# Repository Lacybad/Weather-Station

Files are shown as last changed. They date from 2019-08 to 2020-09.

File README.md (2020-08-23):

# Weather Station


This weather station uses an ESP8266 (WeMos D1 Mini), a TFT KMR-1.8 LCD display, a PIR
motion sensor, BJTs and a photoresistor for the display brightness, and an optional 1-wire
temperature sensor (no code for it right now).

This weather station uses darksky for the forecast with a free account. It displays the
current weather temperature, a high and low, and the next two days.

In Settings.h (or MiscSettings.h), add the GPS coordinates, wifi information, and timezone
to make the system work.

This project's PCB was made using JLCPCB. Using the cheapest shipping, it took 6 days to
LAX, a week in customs, and then 3-5 days to a location in the US.

## Icons / Other Code

The icons used for this project are from
[erikflowers](https://github.com/erikflowers/weather-icons).  Using the makefile command
`make imageConvert` converts the images in the folder weather-icons/svg to bmps in a data
folder. This folder can then be uploaded to the ESP8266 using the
[data-uploader](https://github.com/esp8266/arduino-esp8266fs-plugin), which uploads the
data in the /data folder to the SPIFFS file system. It is recommended if using the D1 mini
to have at least 1 MB of storage, and the images take up 124.0 KiB of space.

Other code for this project is from Bodmer's TFT\_eSPI library example for the
[BMP\_functions.ino](https://github.com/Bodmer/TFT_eSPI/blob/master/examples/Generic/TFT_SPIFFS_BMP/BMP_functions.ino),
and converted to work as a C++ library. The modified
[cpp](https://github.com/mwyoung/Weather-Station/blob/master/src/BMP_functions.cpp),
[h](https://github.com/mwyoung/Weather-Station/blob/master/src/BMP_functions.h) and
[license](https://github.com/mwyoung/Weather-Station/blob/master/src/BMP_functions_license.txt)
are in the src directory.

All other libraries (with given versions used) are not really modified from the source
(besides the [TFT\_eSPI v1.4.20](https://github.com/Bodmer/TFT_eSPI) for the pins and
display), and include [ESP8266 Board v2.5.2](https://github.com/esp8266/Arduino) with docs
[ESP8266Wifi and WiFiClientSecure](https://arduino-esp8266.readthedocs.io/en/latest/esp8266wifi/readme.html),
[ArduinoJson v6.13.0](https://github.com/bblanchon/ArduinoJson),
[BearSSL v1.4.0](https://github.com/arduino-libraries/ArduinoBearSSL),
[SPI - ESP8266](https://github.com/esp8266/Arduino/blob/master/libraries/SPI/SPI.h),
[Ticker - ESP8266](https://github.com/esp8266/Arduino/blob/master/libraries/Ticker/src/Ticker.h),
[Timezone v1.2.2](https://github.com/JChristensen/Timezone) and
[TimeLib v1.5.0](https://github.com/PaulStoffregen/Time).

## Data Source
This project originally used DarkSky as a source but moved to
[OpenWeatherMap](https://openweathermap.org/darksky-openweather) after DarkSky shut down
their API. The DarkSky branch in this repo contains the original code that was working
with that API.

## Schematic



For the PCB, the [d1\_mini\_kicad](https://github.com/jerome-labidurie/d1_mini_kicad)
library was used along with the
[digikey-kicad-library](https://github.com/Digi-Key/digikey-kicad-library) and a few
default libraries KiCad for the transistors. The parts can be found in the
[DigiKey purchase list](https://github.com/mwyoung/Weather-Station/blob/master/weatherPCB/DigikeyCartExample.csv),
and this csv file can be uploaded to digikey to buy the parts. Extra parts are included as
backup for buying parts along with buying a large quantity means cost savings. It is also
possible to use a check to save on shipping (could take an extra few days)

Other parts are from Amazon but can be bought on other sites or vendors if it is cheaper.
The parts include a [Wemos d1 mini](https://www.amazon.com/gp/product/B076F53B6S/),
[Photoresistors](https://www.amazon.com/gp/product/B01N0GJ6QP/),
[IR PIR Motion Sensor](https://www.amazon.com/gp/product/B07LF47TRC/),
[LCD Display](https://www.amazon.com/gp/product/B00LSG51MM/),
[Project Boxes](https://www.amazon.com/dp/B07V7X11LJ).

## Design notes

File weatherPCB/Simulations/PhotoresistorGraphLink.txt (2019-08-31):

https://www.desmos.com/calculator/svxpvmprhs

Note: https://wiki.wemos.cc/_media/products:d1:mini_new_v2_2_0.pdf
Wemos D1 mini has a 1.0V ADC, but on A0 has a voltage divider (220k and 100k) to 1.03V

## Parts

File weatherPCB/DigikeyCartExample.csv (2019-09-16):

Index | Quantity | Part Number | Manufacturer Part Number | Description | Customer Reference | Available | Backorder | Unit Price | Extended Price USD
1 | 10 | 478-3188-ND | SR215C104KAR | CAP CER 0.1UF 50V X7R RADIAL |  | 10 | 0 | 0.135 | 1.35
2 | 10 | 2N4401-APCT-ND | 2N4401-AP | TRANS NPN 40V TO92 |  | 10 | 0 | 0.17 | 1.7
3 | 10 | 2N4403-APCT-ND | 2N4403-AP | TRANS PNP 40V TO92 |  | 10 | 0 | 0.17 | 1.7
4 | 50 | CF14JT220RCT-ND | CF14JT220R | RES 220 OHM 1/4W 5% AXIAL |  | 50 | 0 | 0.022 | 1.1
5 | 50 | CF14JT4K70CT-ND | CF14JT4K70 | RES 4.7K OHM 1/4W 5% AXIAL |  | 50 | 0 | 0.022 | 1.1
6 | 50 | CF14JT10K0CT-ND | CF14JT10K0 | RES 10K OHM 1/4W 5% AXIAL |  | 50 | 0 | 0.022 | 1.1
7 | 10 | S7036-ND | PPPC031LFBN-RC | CONN HDR 3POS 0.1 GOLD PCB |  | 10 | 0 | 0.351 | 3.51

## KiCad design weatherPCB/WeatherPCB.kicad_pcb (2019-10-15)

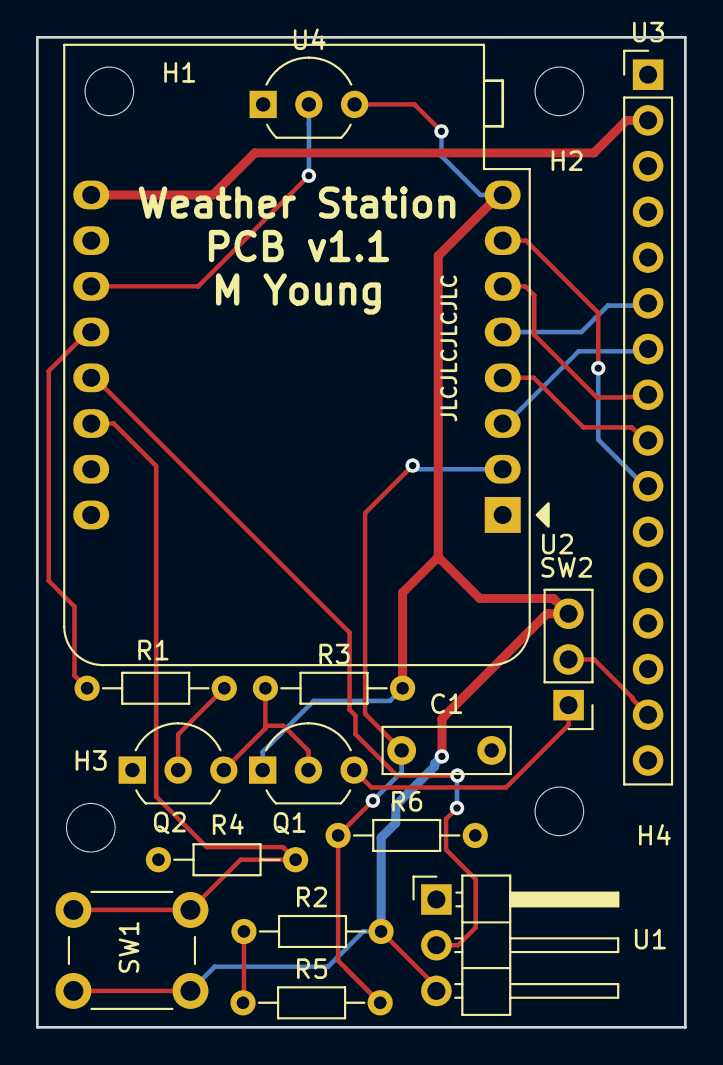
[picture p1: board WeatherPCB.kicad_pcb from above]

Board: 2 copper layers, 36.0 x 55.0 mm, 19 parts (0 on the bottom side), 18 nets.

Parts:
C1: 0.1u; C_Disc_D7.0mm_W2.5mm_P5.00mm
H1, H2, H3, H4: MountingHole; MountingHole_2.7mm
Q1: 2N4403-ND; TO-92_Inline_Wide
Q2: 2N4401-ND; TO-92_Inline_Wide
R1, R3: 4.7k; R_Axial_DIN0204_L3.6mm_D1.6mm_P7.62mm_Horizontal
R2: 220; R_Axial_DIN0204_L3.6mm_D1.6mm_P7.62mm_Horizontal
R4, R6: 10k; R_Axial_DIN0204_L3.6mm_D1.6mm_P7.62mm_Horizontal
R5: 70-36k; R_Axial_DIN0204_L3.6mm_D1.6mm_P7.62mm_Horizontal
SW1: SW_Push; SW_PUSH_6mm_h5mm
SW2: SW_SPDT; Pin_Header_Straight_1x03_Pitch2.54mm
U1: PIR_MTN_SNR; Pin_Header_Angled_1x03_Pitch2.54mm
U2: WeMos_mini; WEMOS_D1_mini_light
U3: TFTLCD_ST7735R; Pin_Header_Straight_1x16_Pitch2.54mm
U4: DS1822; TO-92_Inline_Wide

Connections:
+3V3: Q1.1, R2.1, R3.2, SW1.1, SW2.3, U1.3, U2.8, U4.3
+5V: U2.9, U3.2
GND: C1.2, Q2.1, R4.2, R6.2, U1.1, U2.10, U3.1, U3.16, U4.1
unnamed: C1.1, R5.2, R6.1, U2.2
unnamed: Q1.2, Q2.3, R3.1
unnamed: Q1.3, SW2.1
unnamed: Q2.2, R1.1
unnamed: R1.2, U2.12
unnamed: R2.2, R5.1
unnamed: R4.1, SW1.2, U2.14
unnamed: SW2.2, U3.15
unnamed: U1.2, U2.13
unnamed: U2.3, U3.7
unnamed: U2.4, U3.9
unnamed: U2.5, U3.6
unnamed: U2.6, U3.8
unnamed: U2.7, U3.10
unnamed: U2.11, U4.2

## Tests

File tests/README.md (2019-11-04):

# Examples used to test certain functions for the Weather program

TFT\_Display - Used to test the display, height, pwm, and photoresistor

Motion - Used to test the pir motion sensor

BearSSL\_Weather - Used to test the certificate of the Darksky website

[SPIFFS\_REMOVE\_ALL](https://github.com/mwyoung/SPIFFS_Remove_All)

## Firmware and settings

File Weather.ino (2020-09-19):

/*
    Weather with display
    Miles Young, 2019-2020
 */

//Wifi
#include <ESP8266WiFi.h>
#include <WiFiClientSecure.h>
#include <ArduinoJson.h>
#include "src/weatherClass.h"
//#include "src/cert.h"       //location for cert in memory
#include "Settings.h"       //settings file
//display //drivers - greentab, blacktab+inversion(orange)
//For TFT_eSPI, in User_Setup.h, set TFT_DC PIN_D0 and TFT_RST PIN_D6
#include <TFT_eSPI.h> //!!D6=RST!!,!!D0=A0/DC!!,D8=CS,D7=SDA,D5=SCL
#include <SPI.h>
#include "src/BMP_functions.h"
#include <Ticker.h> //timer interrupts for brightness
//file system
//use fs::File for SPIFFS, sd::File for SD if needed
#define FS_NO_GLOBALS
#include <FS.h>

#include <Timezone.h>
#include <TimeLib.h>

/* include a MiscSettings.h or Settings.h file for these defs
STASSID, STAPSK, API_KEY, FORECAST_LOC, UPDATE_INTERVAL, PIR_TIME,
PIR_ON_TIME, PIR_OFF_TIME, DAYLIGHT_RULE_CONFIG, STANDARD_RULE_CONFIG
*/
//uncomment to print debug, from https://forum.arduino.cc/index.php?topic=46900.0
//hint - when debugging, change the times to trigger things faster...
//#define DEBUG
#ifdef DEBUG
    //#define SHOW_BRIGHTNESS
    //#define SHOW_MOTION
    #define DEBUG_PRINT(str)    Serial.print(str)
    #define DEBUG_PRINTLN(str)  Serial.println(str)
#else
    #define DEBUG_PRINT(str)
    #define DEBUG_PRINTLN(str)
#endif

//uncomment for approx temp (can be 10 deg inaccurate vs other sources)
//#define TEMPAPPROX

//display constants
#define DP_W 128        //display used, need to change if using different size
#define DP_HALF_W (DP_W >> 1)
#define DP_H 160
#define DP_HALF_H (DP_H >> 1)
#define LARGE_ICON 44
#define SMALL_ICON 20
#define TIME_ICON 8     //size of time XX:XX XM
#define FS1 8           //font size height 1
#define FSX1 6          //font size width 1
#define FS2 16
#define FSX2 8
#define FS4 26          //could be 32
//FS6=48, FS7=56/48, FS8=56/75  //either or
#define displayUpdate 1000  //in ms
#define pwmShift 9          //also change brightness max
#define pwmJump 8           //min difference
#define pwmRange (1<<pwmShift)-1 //max range
#define pwmFreq 1000      //1kHz frequency
#define pwmOut D3       //output pin for brightness
#define pirPin D2
#define buttonPin D1
#define UNIX_SECOND 1000UL //1000 uS
#define UNIX_MINUTE UNIX_SECOND*60UL
#define DELAYTIME 20*UNIX_MINUTE

// Constant variables
const char *ssid = STASSID;
const char *password = STAPSK;
const char *host = "api.openweathermap.org";
#ifdef USE_CERT
    const int httpsPort = 443;
    const String httpsProtocol="HTTP/1.1";
#else
    const int httpsPort = 80; //is http
    const String httpsProtocol="HTTP/1.0";
#endif
const size_t capacity = 8*JSON_ARRAY_SIZE(1) + JSON_ARRAY_SIZE(2) + JSON_ARRAY_SIZE(8) +
    18*JSON_OBJECT_SIZE(4) + 9*JSON_OBJECT_SIZE(6) + 5*JSON_OBJECT_SIZE(14) +
    4*JSON_OBJECT_SIZE(15) + 4000;

const String forecastType = "/data/2.5/onecall";
//const String FORECAST_LOC //see define location
const String forecastDetails = "exclude=minutely,hourly,flags,alerts";
const String forecastStr = forecastType + "?" + FORECAST_LOC + "&" + forecastDetails +
    "&units=" + UNITS + "&appid=" + API_KEY;

#define SUNRISE_ICON "sunrise"
#define SUNSET_ICON "sunset"

//global variables - modifiable
TFT_eSPI tft = TFT_eSPI(); //start library
Ticker tftBrightness;

//weather variables
Weather currentWeather;
#define dailyWeatherSize 3
Weather dailyWeather[dailyWeatherSize]; //weather for today, tomorrow, and day+1
int16_t timezoneOffset = 0;
bool haveSetup = false;

//display vars
uint16_t cursorX;
uint16_t cursorY;
char displayOutput[10];
volatile uint16_t rawBrightness; //10 bit number
volatile uint16_t newBrightness;
volatile uint16_t oldBrightness = 1;
volatile bool displayOn = false;

//motion vars
volatile unsigned long lastUpdateTime = 0;
volatile unsigned long currentTime = 0;
volatile unsigned long currentLocalTime = 0; //if not getting ntp time
volatile uint8_t currentHour = 0;
volatile unsigned long pirTime = 0; //last updated
bool pirLast = LOW;
bool pirInput = LOW;
bool buttonLast = LOW;
bool buttonInput = LOW;

//function defs
void LED(bool led_output);
void updateBrightness();
void displayOnOff();
void setBrightness(uint8_t newBrightness);
void setup();
void loop();
void startWeather();
void setClock();
bool getWeather();
void printWeatherDisplay();
inline void printTFTSpace(uint8_t i);
void timeLocalStr(time_t getTime);
void timeStr(time_t getTime);
void setLocalTime(time_t getLocalTime);
void colorPrecip(int color);
void colorPrecipIntensity(float color);
void colorBlueBounds(uint16_t blueAmt);
void colorHumid(int color);
void printPrecip(const String typeWater, int water, uint8_t space);
void printPrecipIntensity(float waterAmt, uint8_t space);
void printHumid(const String typeWater, int water, uint8_t space);
void colorTemp(int color);
int getColorTemp(int color);
void printTempCenter(int tempH, int tempL, uint8_t space, uint8_t fontSize,
        uint8_t textWidth);
void printTemp(int tempH, int tempL, uint8_t space);
inline uint16_t rgbToHex(uint8_t red, uint8_t green, uint8_t blue);
bool printWeatherSerial();
void printIcon(const char *icon);
int checkWeatherIcon(const char *icon);
inline void clearScreen(int textSize);
void flashScreen();
void connectToWifi();
void disconnectWifi();

//flips the LED, is a wrapper function due to ESP8266 having inverse LED
void LED(bool led_output){
    digitalWrite(LED_BUILTIN, !led_output); //need to flip the led
}

//updates the current brightness, changes slowly
void updateBrightness(){
    rawBrightness = analogRead(A0);
    newBrightness = rawBrightness>>(10-pwmShift); //change range: 0-2^(10-x) range

    if (newBrightness < 1){
        newBrightness = 1; //never be zero or else off
    }
    //jump function
    if (abs(newBrightness-oldBrightness) > pwmJump){
        oldBrightness = newBrightness; //jump if large difference
    }
    if (newBrightness > oldBrightness){
        oldBrightness++;
    }
    else if (newBrightness < oldBrightness){
        oldBrightness--;
    }
    setBrightness(oldBrightness);
    //else - no change
#ifdef SHOW_BRIGHTNESS
    DEBUG_PRINT("b: ");
    DEBUG_PRINT(newBrightness);
#endif
}

//turns the display off (along with brightness) or on
void displayOnOff(){
    if (displayOn == false){
        DEBUG_PRINTLN("Turning display on");
        tftBrightness.attach_ms(displayUpdate, updateBrightness); //call every 500ms
        flashScreen(); //clear screen
        updateBrightness();
        displayOn = true;
#ifdef DEBUG
        LED(true);
#endif
    }
    else {
        DEBUG_PRINTLN("Turning display off");
        tftBrightness.detach();
        flashScreen(); //clear screen
        setBrightness(0);
        displayOn = false;
#ifdef DEBUG
        LED(false);
#endif
    }
}

//force sets the brightness of the display
void setBrightness(uint8_t newBrightness){
    analogWrite(pwmOut, newBrightness);
}

//initial setup of the program
void setup() {
    pinMode(LED_BUILTIN, OUTPUT); //LED, GPIO 2, D4
    LED(HIGH);

#ifdef DEBUG
    Serial.begin(115200);
    DEBUG_PRINTLN("\nStartup");
    DEBUG_PRINT("Brightness range: ");
    Serial.println(pwmRange, BIN);
#endif

    wifi_set_sleep_type(MODEM_SLEEP_T); //just turns off WiFi temporary

    analogWriteRange(pwmRange); //display brightness setup
    analogWriteFreq(pwmFreq);
    pinMode(pwmOut, OUTPUT);
    analogWrite(pwmOut, 1); //start at lowest brightness
    displayOn = false;
    displayOnOff();
    tft.init(); //start display
    tft.setRotation(2);

    clearScreen(2); //start at top, font size 2
    if ((tft.width() != DP_W) && (tft.height() != DP_H)){
        DEBUG_PRINT("DISPLAY FORMATTING NOT GUARANTEED");
    }

    if (!SPIFFS.begin()){
        DEBUG_PRINTLN("SPIFFS init failed...");
        while (1) { delay(1); } //stop program
    }
    DEBUG_PRINTLN("SPIFFS init");

#ifdef PIR_TIME
    pinMode(pirPin, INPUT);
#endif
    pirTime = millis(); //for right now, blank value
    pinMode(buttonPin, INPUT);
    LED(LOW);

    connectToWifi();
    startWeather();
#ifdef DEBUG
    tft.setCursor(DP_W-8,0,1);
    tft.print("s");
    currentHour = hour(now());
    DEBUG_PRINT("Hour: "); DEBUG_PRINTLN(currentHour);
#endif
}

//Checks for motion, button press, and update time
void loop() {
    currentTime = millis(); //time since started

#ifdef PIR_TIME
    currentHour = hour(now());
#ifdef PIR_OFF_TIME_MORNING
    if (currentHour >= PIR_ON_TIME || currentHour < PIR_OFF_TIME){ //only during day
#else
    if (currentHour >= PIR_ON_TIME && currentHour < PIR_OFF_TIME){ //only during day
#endif
        pirInput = digitalRead(pirPin);

        if ((pirInput == HIGH) && (pirLast == LOW)){
           //turn on display...
            pirTime = millis();

            if (displayOn == false){
                displayOnOff();
                printWeatherDisplay(); //just turned on...
                DEBUG_PRINTLN("Display Motion Updated...");
            }
#ifdef UPDATE_INTERVAL_MOTION
            if ((lastUpdateTime + UPDATE_INTERVAL_MOTION*UNIX_MINUTE) <= currentTime){
#else
            if ((lastUpdateTime + UPDATE_INTERVAL*UNIX_MINUTE) <= currentTime){
#endif
                DEBUG_PRINTLN("Motion update");
                startWeather(); //only get new data after a period
            }
#ifdef DEBUG
            tft.setCursor(DP_W-8,0,1);
            tft.print("m");
#ifdef SHOW_MOTION
            DEBUG_PRINT("M ");
#endif
#endif
        }
        pirLast == pirInput; //move to last
    }
    else {
        delay(450); //longer sleep at night
    }
#endif
    //turn off if no motion for a while, always (no sleep hours)
    if ((displayOn == true) && ((pirTime + PIR_TIME*UNIX_SECOND) <= currentTime)){
        DEBUG_PRINTLN("Auto turnoff");
        displayOnOff(); //not triggered for a while
    }

    //button function
    buttonInput = digitalRead(buttonPin);
    if ((buttonInput == HIGH) && (buttonLast == LOW)){
        DEBUG_PRINTLN("Button Pressed");
        if (displayOn == false){
            displayOnOff();
        }
        startWeather(); //force get new data
#ifdef DEBUG
        tft.setCursor(DP_W-8,0,1);
        tft.print("b");
#endif
    }
    buttonLast = buttonInput; //update

    if ((lastUpdateTime + UPDATE_INTERVAL*UNIX_MINUTE) <= currentTime){
        DEBUG_PRINTLN("Auto updated");
        //flashScreen(); //don't clear screen yet
        startWeather();
#ifdef DEBUG
        tft.setCursor(DP_W-8,0,1);
        tft.print("a");
#endif
    }
    delay(50);
}

//checks the parsing of the weather, updates display and update time
void startWeather(){
    bool output = getWeather();
    if (output == true){
        if(haveSetup){
            DEBUG_PRINTLN("----------\nFlash display");
            flashScreen(); //flash screen to refresh colors, not on boot
        }

        printWeatherDisplay();
        printWeatherSerial();
        pirTime = millis(); //update last time updated
        lastUpdateTime = millis();
    }
    else {
        DEBUG_PRINTLN("Parse FAILED");
    }
}

//set time via NTP, for tls (X.509) certificate
//From ESP8266 example HTTPSRequestCSCertAxTLS
void setClock() {
    DEBUG_PRINT("Setting time using SNTP: ");
    //timezone, daylightoffset, servers
    configTime(0, 0, "pool.ntp.org", "time.nist.gov"); //utc time
    time_t now = time(nullptr);
    while (now < 8 * 3600 * 2) {
        delay(500);
        DEBUG_PRINT(".");
        now = time(nullptr);
    }
    DEBUG_PRINTLN("");
    setLocalTime(now);
    //struct tm timeinfo;
    //gmtime_r(&now, &timeinfo);
    //DEBUG_PRINT("Current time: ");
    //DEBUG_PRINT(asctime(&timeinfo));
}

//gets the weather from api, formats json
bool getWeather() {
    tft.fillRect(0,DP_H-FS1, DP_W, FS1, TFT_BLACK); //clear line
    tft.setCursor(0,DP_H-FS1,1);
    tft.println("Src: OpenWeatherMap");

#ifdef USE_CERT
    DEBUG_PRINTLN("Setting up cert");
    BearSSL::WiFiClientSecure client;
    BearSSL::X509List cert(digicert);
    client.setTrustAnchors(&cert);
    //client.setInsecure(); //no https

    setClock(); //set clock, update when getting new as drift occurs on uC
#else
    // Connect to remote server
    WiFiClient client;
#endif

    DEBUG_PRINT("connecting to ");
    DEBUG_PRINTLN(host);
    if (!client.connect(host, httpsPort)) {
        DEBUG_PRINTLN("Connection failed");
        tft.fillRect(0,DP_H-FS1, DP_W, FS1, TFT_BLACK); //clear line
        tft.setCursor(0,DP_H-FS1,1);
#ifdef USE_CERT
        tft.println("Connection fail\nCould be cert fail");
#else
        tft.println("Connection fail");
#endif
        client.stop();
        if(displayOn == true){
            setBrightness(5);
        }
        delay(DELAYTIME); //stop for delay time
        ESP.restart(); //restart to avoid loop
        return false; //should never get here
    }
    else {
        DEBUG_PRINTLN("Getting forecast for: ");
        DEBUG_PRINTLN("https://" + String(host) + forecastStr);

        client.print(String("GET ") + forecastStr + " " + httpsProtocol + "\r\n" +
                "Host: " + host + "\r\n" +
                "User-Agent: ESP8266\r\n" +
                "Connection: close\r\n\r\n");

        DEBUG_PRINTLN("request sent");
        while (client.connected() || client.available()) {
            if (client.available()){
                String line = client.readStringUntil('\n');
                //DEBUG_PRINTLN(line); //print header
                if (line == "\r") {
                    DEBUG_PRINTLN("headers received");
                    tft.fillRect(0,DP_H-FS1, DP_W, FS1, TFT_BLACK); //clear line
                    tft.setCursor(0,DP_H-FS1,1);
                    tft.print("Got forecast");
                    break;
                }
            }
        }
    }

    //help from https://arduinojson.org/v6/assistant/
    DEBUG_PRINT("Created doc with size:"); DEBUG_PRINT(capacity); DEBUG_PRINT(" -> ");
    DynamicJsonDocument doc(capacity);
    tft.println("...");
    DeserializationError error = deserializeJson(doc, client.readStringUntil('\n'));
    tft.println("...");
    tft.setCursor(0,DP_HALF_H,1);
    DEBUG_PRINT("Parse Status: ");

    if (error){
        DEBUG_PRINT("Parse failed - ");
        DEBUG_PRINTLN(error.c_str());
        tft.println("JSON parse failed");
        tft.println(error.c_str());
        delay(DELAYTIME);
        return false;
    }
    else {
        //check if can get any key
        DEBUG_PRINTLN("Parse succeeded");
        const char *error = doc["timezone"];
        if (error == NULL){
            DEBUG_PRINT("Checking if message exists: ");
            const char *msg = doc["message"];
            if (msg != NULL){
                DEBUG_PRINTLN(msg);
                clearScreen(1);
                tft.println(msg);
            }
            return false;
        }
    }

    DEBUG_PRINTLN("Getting Data");
    bool output = currentWeather.setupWeather(doc["current"], false);
    if (output == false){
        DEBUG_PRINTLN("Setup failed for current");
        return false;
    }
    else {
        DEBUG_PRINTLN("Setup current");
    }

    timezoneOffset = doc["timezone_offset"];
    //setTime(currentWeather.getTime());
    setLocalTime(currentWeather.getTime()); //set time
    timeLocalStr(currentWeather.getTime());
    DEBUG_PRINT(timezoneOffset); DEBUG_PRINT(" "); DEBUG_PRINT(currentWeather.getTime());
        DEBUG_PRINT(" -> "); DEBUG_PRINTLN(displayOutput);

    //is a work-around - sometimes does not get the icon string correctly after wakeup
    DEBUG_PRINT(" "); DEBUG_PRINTLN(currentWeather.getIcon());

    for (int i=0; i<dailyWeatherSize; i++){
        output = dailyWeather[i].setupWeather(doc["daily"][i], true);
        if (output == false){
            DEBUG_PRINTLN("Setup failed for daily");
            return false;
        }
        else {
            DEBUG_PRINT("Setup daily ");
        }
    }

    DEBUG_PRINTLN("\nDone!");
    lastUpdateTime = millis();
    client.stop();
    return true;
}

//outputs weather to the display
void printWeatherDisplay(){
    clearScreen(1);
    uint16_t iconY = 0;
    uint16_t iconX = 0;
    int tempVal = 0;
    int tempHigh = 0;
    int tempLow = 0;
    if(!currentWeather.getSetup()){
        tft.println("Not setup");
        return;
    }

    //current weather
    tft.setCursor(tft.getCursorX()+1, tft.getCursorY());
    tft.print("Updated: ");
    timeLocalStr(currentWeather.getTime());
    tft.println(displayOutput);
    cursorY = tft.getCursorY();
    tft.setCursor((DP_HALF_W - LARGE_ICON)>>1, cursorY+1);
    printIcon(currentWeather.getIcon());

    //Current Temp
    //tft.setCursor(DP_HALF_W, cursorY+FS1-1, 2); tft.print("~");
    tft.setCursor(DP_HALF_W, cursorY, 4);
    //colorTemp(currentWeather.getTemp());
#ifdef TEMPAPPROX
    tft.print(currentWeather.getTempApprox());
#else
    tft.print(currentWeather.getTemp());
#endif
    tft.setTextColor(TFT_WHITE);
    tft.drawCircle(tft.getCursorX()+4, tft.getCursorY()+4, 2, TFT_WHITE); //degree symbol
    tft.setCursor(tft.getCursorX()+10, tft.getCursorY(), 2);
    tft.println("F");
    tft.setCursor(DP_HALF_W, tft.getCursorY()+(FS1>>1)+1, 1);
    printPrecip("Rain:", currentWeather.getPrecipProb(), 2);

    //Temp high/low
    tft.setCursor(DP_HALF_W, tft.getCursorY()+FS1-1, 2);
    printTemp(dailyWeather[0].getTempHigh(), dailyWeather[0].getTempLow(), 4);
    tft.println();

    //Rain/Humidity
    tft.setCursor(tft.getCursorX()+4, tft.getCursorY()-(FS1>>2), 2);
    printPrecip("Rain:", dailyWeather[0].getPrecipProb(), 4);
    tft.setCursor(DP_HALF_W+8, tft.getCursorY());
#ifdef PRECIP_INSTY
    printPrecipIntensity(dailyWeather[0].getPrecipAmt(), 4);
#else
    printHumid("RH:", dailyWeather[0].getHumidity(), 4);
#endif
    tft.println();
    tft.setTextColor(TFT_WHITE);

    //set sunset/rise
    cursorY = tft.getCursorY();
    tft.setCursor(4,cursorY,1);
    timeLocalStr(dailyWeather[0].getSunriseTime());
    tft.println(displayOutput);
    tft.setCursor(DP_HALF_W + (SMALL_ICON>>1)+2, cursorY);
    timeLocalStr(dailyWeather[0].getSunsetTime());
    tft.println(displayOutput);
    cursorY = tft.getCursorY();

    tft.setCursor(DP_HALF_W-(SMALL_ICON>>1), cursorY-(SMALL_ICON>>1)); //divide 2
    if (currentWeather.getTime() < dailyWeather[0].getSunriseTime() ||
            currentWeather.getTime() > dailyWeather[0].getSunsetTime()){
        printIcon(SUNRISE_ICON); //is after sunset or before sunrise
        tft.drawLine(4, cursorY, DP_HALF_W - (SMALL_ICON>>1) - 4, cursorY, TFT_WHITE);
    }
    else {
        printIcon(SUNSET_ICON); //is after sunrise
        tft.drawLine(DP_HALF_W+(SMALL_ICON>>1) + 4, cursorY, DP_W - 4, cursorY, TFT_WHITE);
    }

    tft.setCursor(tft.getCursorX(), tft.getCursorY()+FS1-1);

    //Add some color - draw current temp as a rect, x0,y0,x1,y1
    tft.fillRect(DP_W-2, 0, DP_W, DP_HALF_H-(FS2<<1), getColorTemp(currentWeather.getTempApprox()));

    //next day forecast
    tft.setTextColor(TFT_WHITE);
    cursorY = FS1 + FS4 + (FS2<<1) + FS2 + FS1;
    tft.drawLine(DP_HALF_W - 1, cursorY - (FS1>>2), DP_HALF_W - 1, DP_H - (FS1>>2), TFT_DARKGREY);

    tft.setCursor(8,cursorY - (FS1>>1)+1);
    printIcon(dailyWeather[1].getIcon());
    tft.setCursor(DP_HALF_W+8,tft.getCursorY());
    printIcon(dailyWeather[2].getIcon());

    tft.setCursor(20, cursorY - FS2, 2);
    tft.print(dayShortStr(weekday(dailyWeather[1].getTime())));
    tft.setCursor(DP_HALF_W+20, tft.getCursorY());
    tft.print(dayShortStr(weekday(dailyWeather[2].getTime())));

    tft.setCursor(0,cursorY + (LARGE_ICON - (FS1>>1)));
    printTempCenter(dailyWeather[1].getTempHigh(), dailyWeather[1].getTempLow(), 1,
            FSX2, DP_HALF_W);

    tft.setCursor(DP_HALF_W,tft.getCursorY());
    printTempCenter(dailyWeather[2].getTempHigh(), dailyWeather[2].getTempLow(), 1,
            FSX2, DP_HALF_W);
    tft.println();

    tft.setCursor(4+1,tft.getCursorY()-1,1);
    printPrecip("Rain:", dailyWeather[1].getPrecipProb(), 4);
    tft.setCursor(DP_HALF_W+2+1,tft.getCursorY());
    printPrecip("Rain:", dailyWeather[2].getPrecipProb(), 4);
    tft.println();

    tft.setCursor(4+1,tft.getCursorY());
#ifdef PRECIP_INSTY
    printPrecipIntensity(dailyWeather[1].getPrecipAmt(), 4);
#else
    printHumid("RH:", dailyWeather[2].getHumidity(), 4);
#endif
    tft.setCursor(DP_HALF_W+2+1,tft.getCursorY());
#ifdef PRECIP_INSTY
    printPrecipIntensity(dailyWeather[2].getPrecipAmt(), 4);
#else
    printHumid("RH:", dailyWeather[2].getHumidity(), 4);
#endif
    tft.println();
    tft.setTextColor(TFT_WHITE);

    haveSetup = true;
}

//prints a variable size space
inline void printTFTSpace(uint8_t i){
    tft.setCursor(tft.getCursorX()+i,tft.getCursorY());
}

//converts UTC to timezone
void timeLocalStr(time_t getTime){
    timeStr(getTime + timezoneOffset);
}

//converts a time to AM/PM
void timeStr(time_t getTime){
    snprintf(displayOutput, sizeof(displayOutput), "%02d:%02d ",
            hourFormat12(getTime), minute(getTime));
    if (isAM(getTime)){
        strncat(displayOutput,"AM", 2);
    }
    else {
        strncat(displayOutput, "PM", 2);
    }
}

//sets the current local time
void setLocalTime(time_t getLocalTime){
    currentLocalTime = getLocalTime + timezoneOffset;
    setTime(currentLocalTime);
#ifdef debug
    DEBUG_PRINTLN("Set local time to:");
    timeStr(getLocalTime);
    DEBUG_PRINT(displayOutput);
#endif
}

//changes the color of rain to stand out more
void colorPrecip(int color){
    if (color > 40){
        colorBlueBounds(color>>2);
    }
    else {
        tft.setTextColor(TFT_WHITE);
    }
}

//changes the color of rain to stand out more
void colorPrecipIntensity(float color){
    if (color >= 0.01){
        colorBlueBounds((uint16_t)color*100);
    }
    else {
        tft.setTextColor(TFT_WHITE);
    }
}

//checks bounds of colors
void colorBlueBounds(uint16_t blueAmt){
    if (blueAmt > 255){
        blueAmt = 255;
    }
    tft.setTextColor(rgbToHex(0, 255 - blueAmt, 255));
}
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

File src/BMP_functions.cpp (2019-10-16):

#include <FS.h>
#include <TFT_eSPI.h>
#include "BMP_functions.h"
extern TFT_eSPI tft;
// Bodmers BMP image rendering function
// changed to output errors

int8_t drawBmp(const char *filename, int16_t x, int16_t y) {

    if ((x >= tft.width()) || (y >= tft.height())) return 0;

    fs::File bmpFS;

    // Open requested file on SD card
    bmpFS = SPIFFS.open(filename, "r");

    if (!bmpFS)
    {
        Serial.println("File not found");
        return 0;
    }

    int returnVal = 0;
    uint32_t seekOffset;
    uint16_t w, h, row, col;
    uint8_t  r, g, b;

    uint32_t startTime = millis();

    if (read16(bmpFS) == 0x4D42)
    {
        read32(bmpFS);
        read32(bmpFS);
        seekOffset = read32(bmpFS);
        read32(bmpFS);
        w = read32(bmpFS);
        h = read32(bmpFS);

        if ((read16(bmpFS) == 1) && (read16(bmpFS) == 24) && (read32(bmpFS) == 0))
        {
            y += h - 1;

            tft.setSwapBytes(true);
            bmpFS.seek(seekOffset);

            uint16_t padding = (4 - ((w * 3) & 3)) & 3;
            uint8_t lineBuffer[w * 3 + padding];

            for (row = 0; row < h; row++) {
                bmpFS.read(lineBuffer, sizeof(lineBuffer));
                uint8_t*  bptr = lineBuffer;
                uint16_t* tptr = (uint16_t*)lineBuffer;
                // Convert 24 to 16 bit colours
                for (uint16_t col = 0; col < w; col++)
                {
                    b = *bptr++;
                    g = *bptr++;
                    r = *bptr++;
                    *tptr++ = ((r & 0xF8) << 8) | ((g & 0xFC) << 3) | (b >> 3);
                }

                // Push the pixel row to screen, pushImage will crop the line if needed
                // y is decremented as the BMP image is drawn bottom up
                tft.pushImage(x, y--, w, 1, (uint16_t*)lineBuffer);
            }
            Serial.print("Loaded in "); Serial.print(millis() - startTime);
            Serial.println(" ms");
            returnVal = 1;
        }
        else {
            Serial.println("BMP format not recognized.");
            returnVal = 0;
        }
    }
    bmpFS.close();
    return returnVal;
}

// These read 16- and 32-bit types from the SD card file.
// BMP data is stored little-endian, Arduino is little-endian too.
// May need to reverse subscript order if porting elsewhere.

uint16_t read16(fs::File &f) {
    uint16_t result;
    ((uint8_t *)&result)[0] = f.read(); // LSB
    ((uint8_t *)&result)[1] = f.read(); // MSB
    return result;
}

uint32_t read32(fs::File &f) {
    uint32_t result;
    ((uint8_t *)&result)[0] = f.read(); // LSB
    ((uint8_t *)&result)[1] = f.read();
    ((uint8_t *)&result)[2] = f.read();
    ((uint8_t *)&result)[3] = f.read(); // MSB
    return result;
}

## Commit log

2019-08-10 Problems connecting to API
    [Weather.ino]
2019-08-13 Now works in insecure mode, code needs to be fixed, removed some comments
    [Weather.ino]
2019-08-14 Working with ArduinoJson lib
2019-08-19 new setup mostly works, still need to change ArduinoJson conatinsKey
2019-08-20 started printing things on display
2019-08-21 Started on time zone stuff, crashes
    [Weather.ino]
2019-08-21 Time still not working, trying ezTime
    [Weather.ino]
2019-08-21 Moving to time.h, outputs in wrong format right now...
    [Weather.ino]
2019-08-23 Time is 7 hours ahead (UTC), switching to ezTime
2019-08-23 ezTime with OFFSET now is correct, will try smaller libraries with manual timezones
    [Weather.ino]
2019-08-23 Started on weather display prototype
2019-08-27 Edited makefile, started PCB/schematic creation
    [WeatherPCB.kicad_pcb, WeatherPCB.sch]
2019-08-27 Added d1_mini kicad files
    [WeatherPCB.sch, d1_mini_shield.kicad_pcb, d1_mini_shield.sch]
2019-08-27 Added display and wiring
    [WeatherPCB.sch]
2019-08-27 Rename PCB
    [WeatherPCB.kicad_pcb, WeatherPCB.sch, d1_mini_shield.kicad_pcb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]
2019-08-27 Added pin map
2019-08-27 Some graphical issues, displays all information correctly
    [Weather.ino]
2019-08-28 Updates schematic, changed display output a bit
    [WeatherPCB.sch]
2019-08-29 Fixed humidity, added some color, fixed layout
    [Weather.ino]
2019-08-30 Changing default RST pin, adding LTSpice simulation
2019-08-31 Updated schematic for backlighting, renamed pins
    [WeatherPCB.sch]
2019-08-31 Added photoresistor math, display testing example, updated schematic
    [WeatherPCB.sch]
2019-08-31 Added timer interrupt for brightness, can now switch between types of brightness control
2019-09-08 Added PIR motion and button test
2019-09-09 Added PIR and button to schematic
    [WeatherPCB.sch]
2019-09-09 Added button feature
2019-09-09 Updated printing info
2019-09-09 Motion sensor now works
2019-09-12 Reconfigured BJTs on schematic
    [WeatherPCB.sch]
2019-09-13 Started on PCB
    [WeatherPCB.kicad_pcb, WeatherPCB.sch]
2019-09-16 created pcb
    [DigikeyCartExample.csv, WeatherPCB.kicad_pcb, WeatherPCB.sch]
2019-09-17 Rev 1 PCB finished
    [WeatherPCB.kicad_pcb, WeatherPCB.sch]
2019-10-15 Modified PCB for larger resistor sizes and KiCad error with display wiring
    [WeatherPCB.kicad_pcb, WeatherPCB.sch]
2019-10-15 Added space for optional 1-wire temp sensor
    [WeatherPCB.kicad_pcb, WeatherPCB.sch]
2019-10-16 Trying to fix the n/a icon issue
    [Weather.ino]
2019-10-16 Finally fixed n/a icon issue, using a work around to store data
    [Weather.ino]
2019-10-24 Fixed bug with motion
    [Motion.ino, Weather.ino]
2019-10-24 Added code to fix looping bug (hopefully)
    [Weather.ino]
2019-10-26 Fixed screen clearing bug
    [Weather.ino]
2019-10-28 Fixed turnoff time bug
    [Weather.ino]
2019-10-28 Fixed issue with hour time/flashing when updating
    [Weather.ino]
2019-11-01 Moved parts around on schematic, no part changes
    [WeatherPCB.sch]
2019-11-23 fix https request, add brightness jump
    [Weather.ino]
2020-08-22 Started the process, currently broken on parse FAILED after message
    [Weather.ino]
2020-08-30 Reverted back to normal temp from approx/feels like as it was 10 deg inaccurate at times
    [Weather.ino]
2020-09-12 Updated JSON size, fixed error message output
    [Weather.ino]
2020-09-15 Update colors and printing word wrap
2020-09-16 Fix precipitation/rain calculation, update blue color function
    [Weather.ino]
